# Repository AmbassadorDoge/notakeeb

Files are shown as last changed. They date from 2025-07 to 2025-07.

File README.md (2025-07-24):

# This is a Keyboard!

## Description
This is a 65% keyboard that I made to learn more about PCB design & keyboard making! It uses a Raspberry Pi Pico as its microcontroller and I plan to use Akko Penguin switches. On the bottom right of the PCB, there is artwork by [bunnyguy](https://bunnyguy.foo/)!

## Why I Made This
I need a keyboard, and I need to learn pcb design + F360, so why not fulfill both? I also thought this was a fun project, and I learned a lot from researching keyboard components and design! I guess this is a part 2 to the hackpad I made a week earlier.

## Why It's Cool
There are magnets on each side so that decals or wrist rests could be added for customization. There might be keyboard lifts in the making for those side mounts 👀

## Pictures
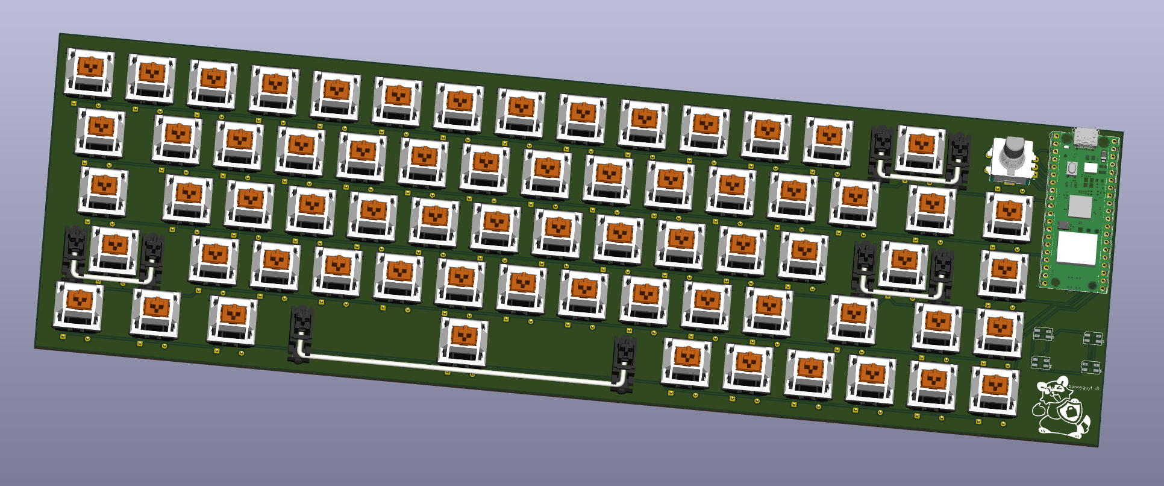
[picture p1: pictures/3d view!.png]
very good

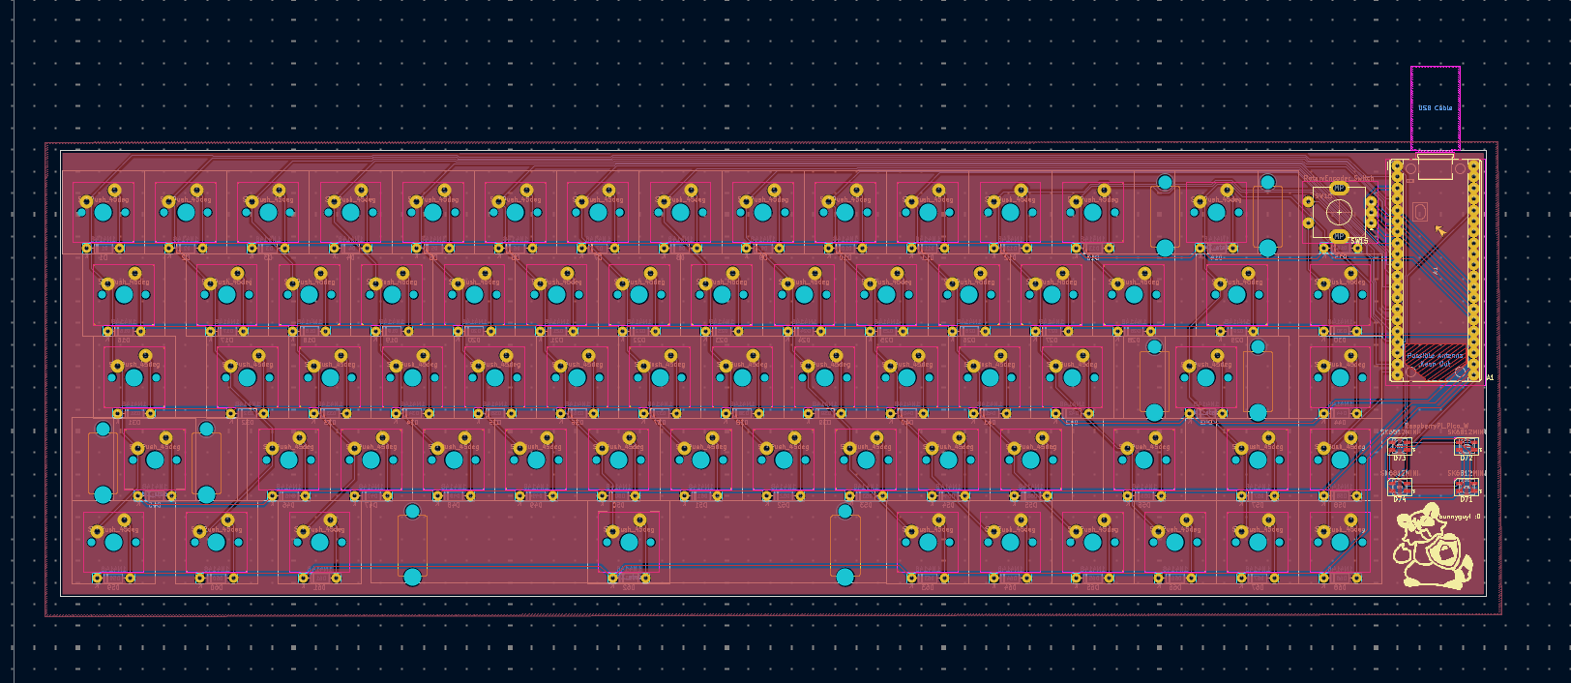
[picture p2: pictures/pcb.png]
good good good

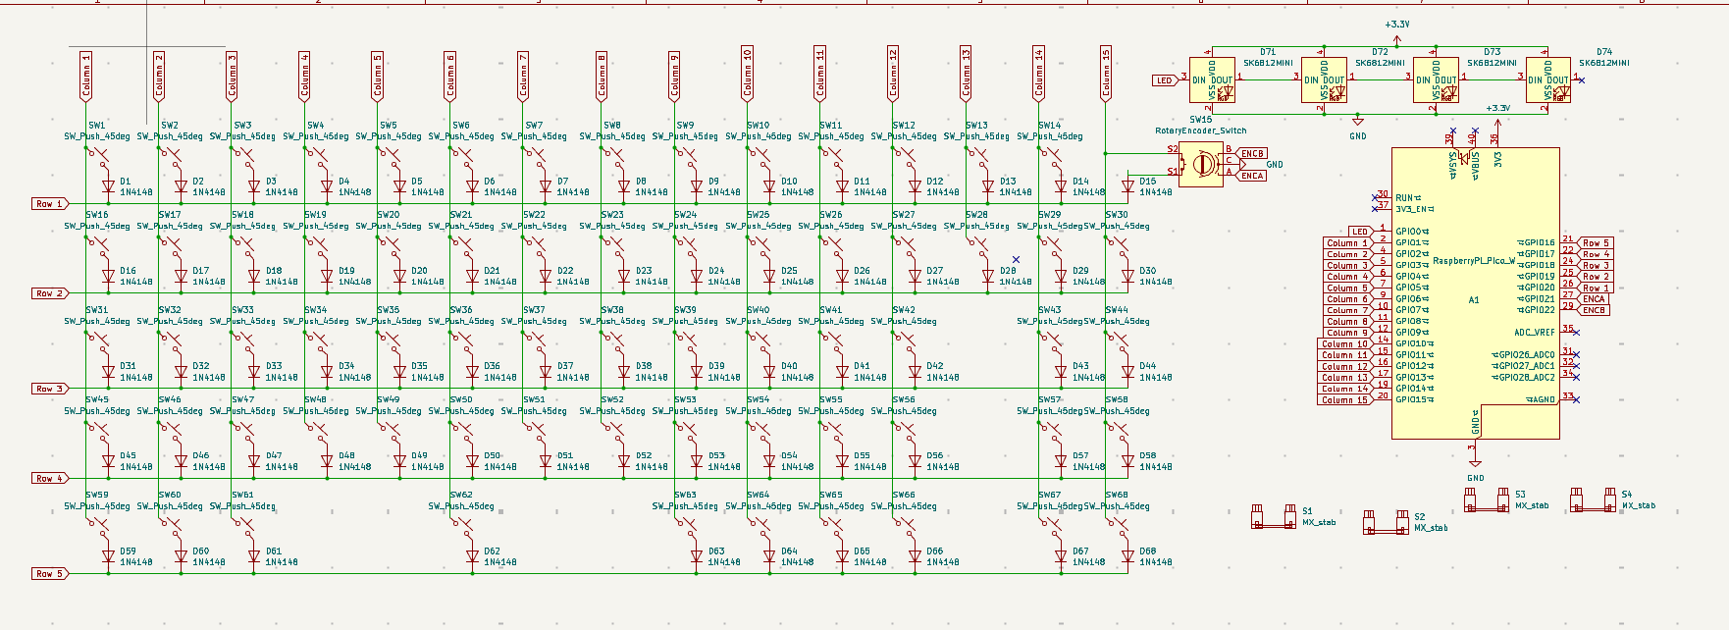
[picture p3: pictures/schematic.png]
good good

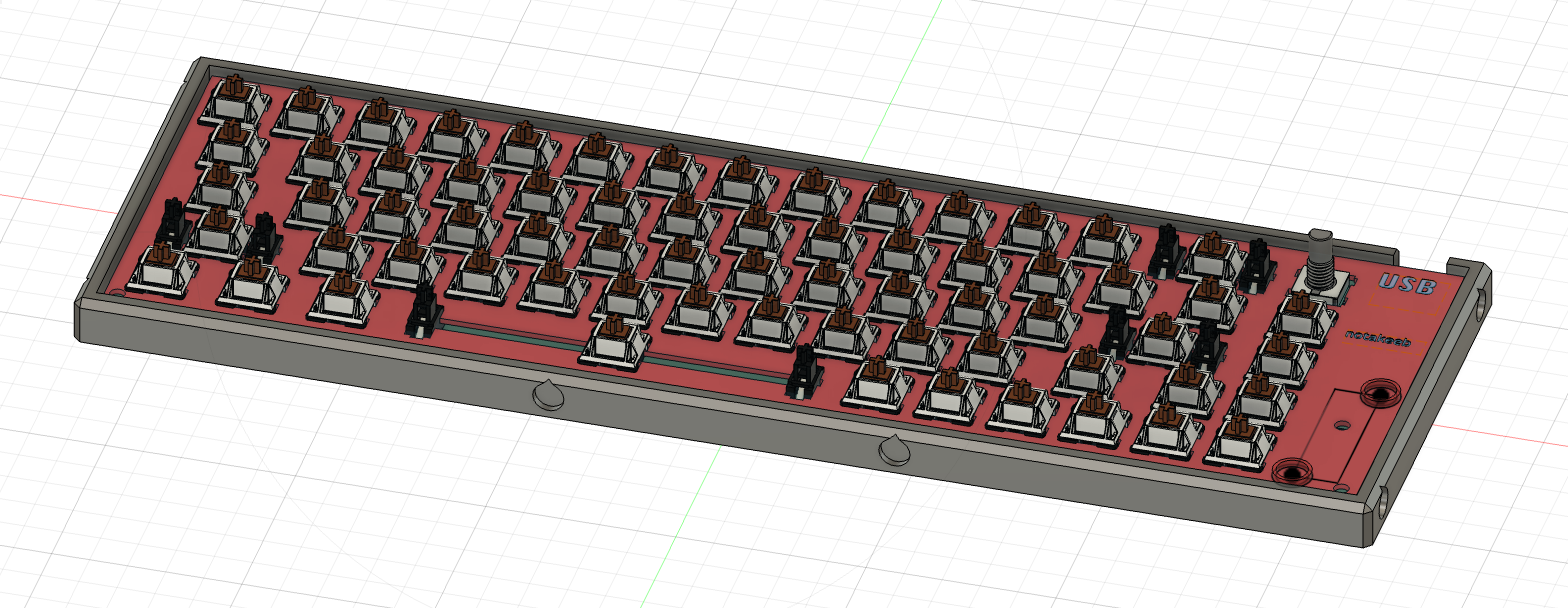
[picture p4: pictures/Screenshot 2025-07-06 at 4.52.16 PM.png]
fusionss

## BOM
| name | qty  | price  | link | notes |
| --- | ---- | --- | --- | --- |
| switches | 2 | 37.98  | [https://www.amazon.com/dp/B0CJY7QN11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](https://www.amazon.com/dp/B0CJY7QN11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) | awesome-mx style |
| keycaps | 1 | 20.5 | [https://www.amazon.com/Rainy75-Gradient-Minimalist-Keyboard-Mechanical/dp/B0F5GLMNFS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](https://www.amazon.com/Rainy75-Gradient-Minimalist-Keyboard-Mechanical/dp/B0F5GLMNFS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) | idk if these work |
| diodes | 1 | 5.99 | [https://www.amazon.com/BOJACK-Switching-IN4148-Electronic-Silicon/dp/B07Q4F3Y5W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](https://www.amazon.com/BOJACK-Switching-IN4148-Electronic-Silicon/dp/B07Q4F3Y5W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) | first thing popped up |
| board | 1 | 7.65 | [https://www.digikey.com/en/products/detail/raspberry-pi/SC0918/16627943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](https://www.digikey.com/en/products/detail/raspberry-pi/SC0918/16627943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) | i think this works |
| fasteners | 1 | 9.99 | [https://www.amazon.com/Mywish-Assortment-Stainless-Washers-Wrenche/dp/B0CQQS6STL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](https://www.amazon.com/Mywish-Assortment-Stainless-Washers-Wrenche/dp/B0CQQS6STL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) | m3 hopefully is good  |
| stabilizers | 1 | 18.99  | [https://www.amazon.com/DUROCK-Stabilizers-Translucent-Keyboard-Mechanical/dp/B0B2RVN19F?th=1](https://www.amazon.com/DUROCK-Stabilizers-Translucent-Keyboard-Mechanical/dp/B0B2RVN19F?th=1) | suggested |
| tape | 1 | 7.99 | [https://www.amazon.com/Resistant-Sublimation-Temperature-Electronics-Polyimide/dp/B07F8TZZ4N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](https://www.amazon.com/Resistant-Sublimation-Temperature-Electronics-Polyimide/dp/B07F8TZZ4N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) | |
| magnets | 1 | 4.51 | [https://www.aliexpress.us/item/3256808695821393.html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](https://www.aliexpress.us/item/3256808695821393.html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) | |
| pcb | 1(5) | 25.04  | | |
| | | 138.64 | 152.1574

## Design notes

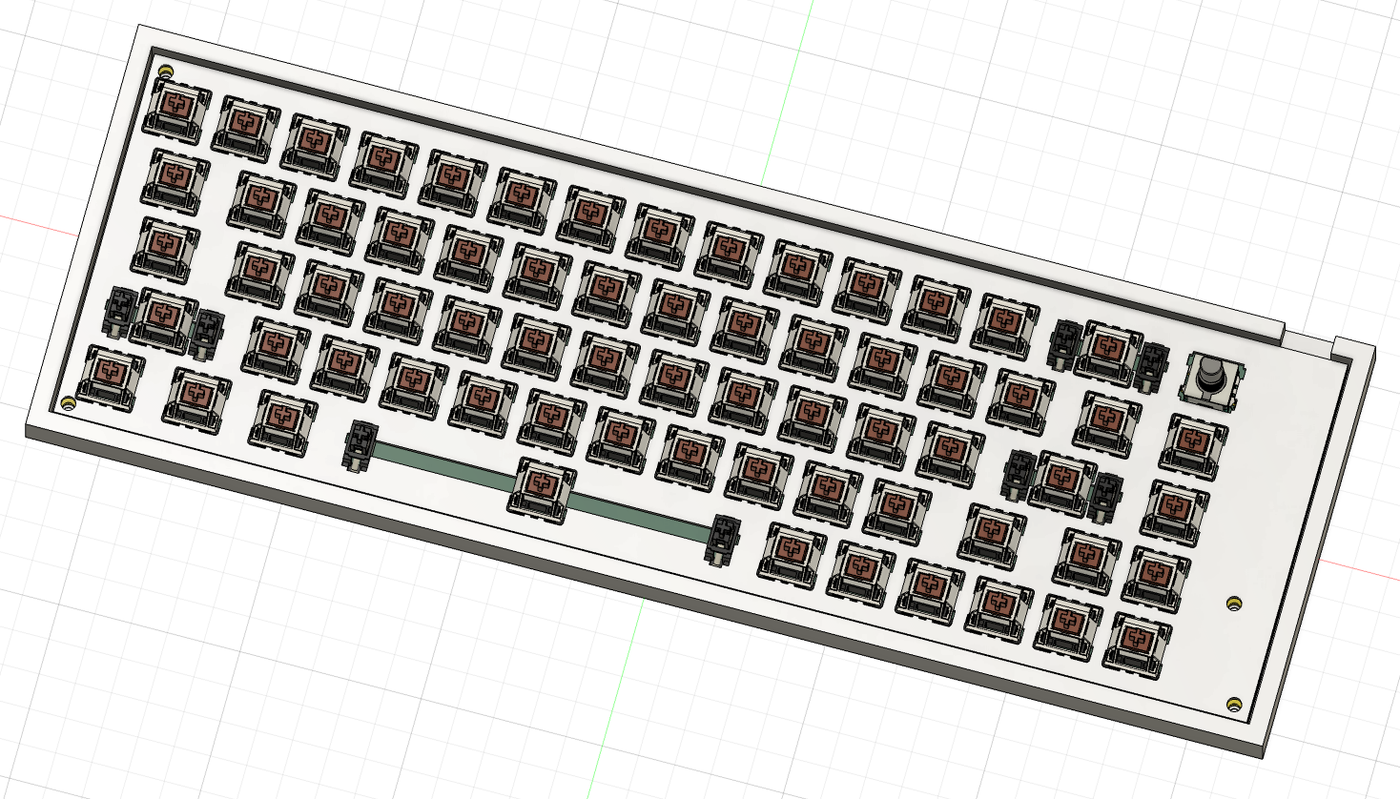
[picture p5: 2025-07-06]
pictures/Screenshot 2025-07-05 at 5.33.53 PM.png

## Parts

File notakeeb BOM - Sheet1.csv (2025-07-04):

name | qty | price | link | notes
switches | 2 | 37.98 | https://www.amazon.com/dp/B0CJY7QN11 | awesome-mx style
keycaps | 1 | 20.5 | https://www.amazon.com/Rainy75-Gradient-Minimalist-Keyboard-Mechanical/dp/B0F5GLMNFS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 | idk if these work
diodes | 1 | 5.99 | https://www.amazon.com/BOJACK-Switching-IN4148-Electronic-Silicon/dp/B07Q4F3Y5W | first thing popped up
board | 1 | 7.65 | https://www.digikey.com/en/products/detail/raspberry-pi/SC0918/16627943?gad_source=1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 | i think this works
fasteners | 1 | 9.99 | https://www.amazon.com/Mywish-Assortment-Stainless-Washers-Wrenche/dp/B0CQQS6STL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 | m3 hopefully is good
stabilizers | 1 | 18.99 | https://www.amazon.com/DUROCK-Stabilizers-Translucent-Keyboard-Mechanical/dp/B0B2RVN19F?th=1 | suggested
tape | 1 | 7.99 | https://www.amazon.com/Resistant-Sublimation-Temperature-Electronics-Polyimide/dp/B07F8TZZ4N
pcb | 1(5) | 25.04
 |  | 134.13

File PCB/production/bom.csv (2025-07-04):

Designator | Footprint | Quantity | Value | LCSC Part #
A1 | RaspberryPi_Pico_Common_THT | 1 | RaspberryPi_Pico_W
D1, D10, D11, D12, D13, D14, D15, D16, D17, D18, D19, D2, D20, D21, D22, D23, D24, D25, D26, D27, D28, D29, D3, D30, D31, D32, D33, D34, D35, D36, D37, D38, D39, D4, D40, D41, D42, D43, D44, D45, D46, D47, D48, D49, D5, D50, D51, D52, D53, D54, D55, D56, D57, D58, D59, D6, D60, D61, D62, D63, D64, D65, D66, D67, D68, D7, D8, D9 | D_DO-35_SOD27_P7.62mm_Horizontal | 68 | 1N4148
D71, D72, D73, D74 | LED_SK6812MINI_PLCC4_3.5x3.5mm_P1.75mm | 4 | SK6812MINI
S1, S2, S4 | STAB_MX_2u | 3 | MX_stab
S3 | STAB_MX_6.25u | 1 | MX_stab
SW1, SW10, SW11, SW12, SW13, SW14, SW16, SW17, SW18, SW19, SW2, SW20, SW21, SW22, SW23, SW24, SW25, SW26, SW27, SW28, SW29, SW3, SW30, SW31, SW32, SW33, SW34, SW35, SW36, SW37, SW38, SW39, SW4, SW40, SW41, SW42, SW43, SW44, SW45, SW46, SW47, SW48, SW49, SW5, SW50, SW51, SW52, SW53, SW54, SW55, SW56, SW57, SW58, SW59, SW6, SW60, SW61, SW62, SW63, SW64, SW65, SW66, SW67, SW68, SW7, SW8, SW9 | SW_MX_1u | 67 | SW_Push_45deg
SW15 | RotaryEncoder_Alps_EC11E-Switch_Vertical_H20mm | 1 | RotaryEncoder_Switch

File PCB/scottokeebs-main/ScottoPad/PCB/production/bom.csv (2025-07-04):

Designator | Footprint | Quantity | Value | LCSC Part #
C0, C1, C2, C3, C4, C5, R0, R1, R2 | TestPoint | 9 | TestPoint
D1, D10, D11, D12, D13, D14, D15, D16, D17, D18, D2, D3, D4, D5, D6, D7, D8, D9 | Diode_SOD-123 | 18 | Diode
S1, S10, S11, S12, S13, S14, S15, S16, S17, S18, S2, S3, S4, S5, S6, S7, S8, S9 | MX_Solder_1.00u | 18 | Keyswitch

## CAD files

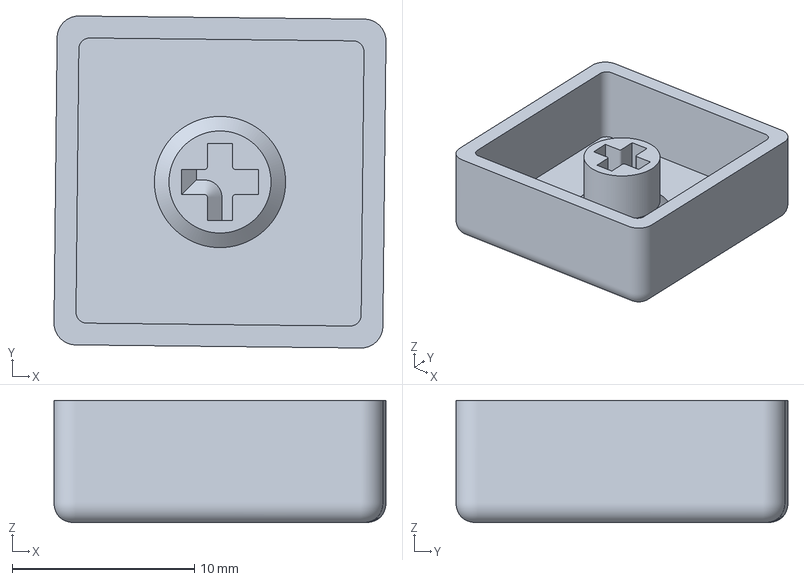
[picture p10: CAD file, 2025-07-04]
PCB/scottokeebs-main/Extras/ScottoCaps/Flat/Legends/Slash.3mf
18.2 x 18.2 x 6.70 mm
Slash_Keycap
Slash_Text

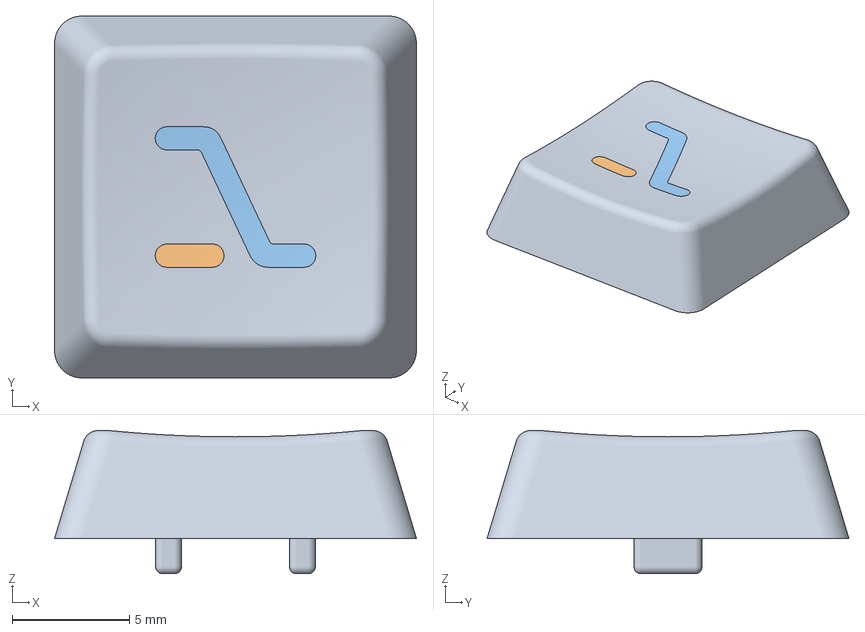
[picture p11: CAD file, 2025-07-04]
PCB/scottokeebs-main/Extras/ScottoCaps/Scooped/Choc/Legends/16x16/Option - Icon (16x16).3mf
15.4 x 15.4 x 6.11 mm
Keycap

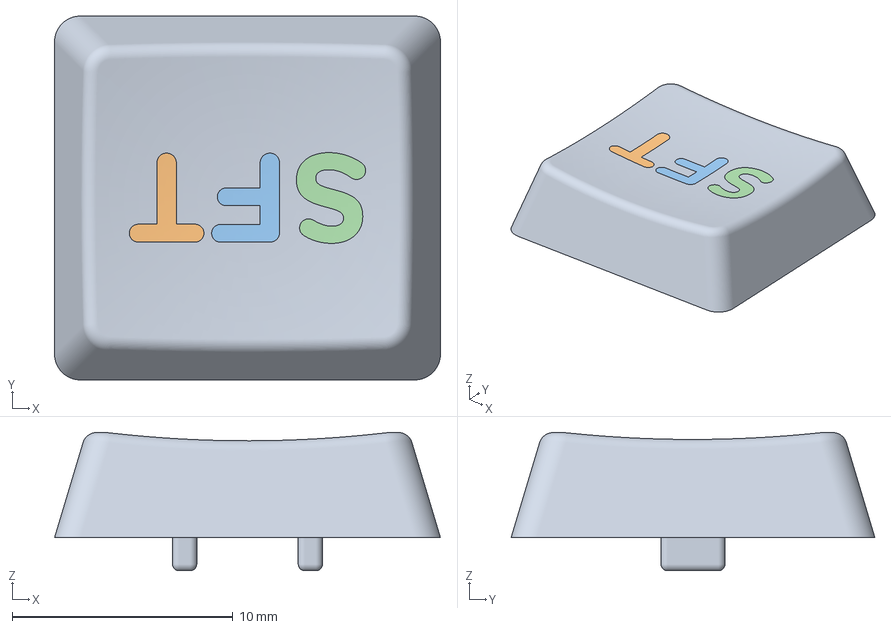
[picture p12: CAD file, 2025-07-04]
PCB/scottokeebs-main/Extras/ScottoCaps/Scooped/Choc/Legends/18x17/Shift (18x17).3mf
17.5 x 16.5 x 6.28 mm
Keycap
T
F
S

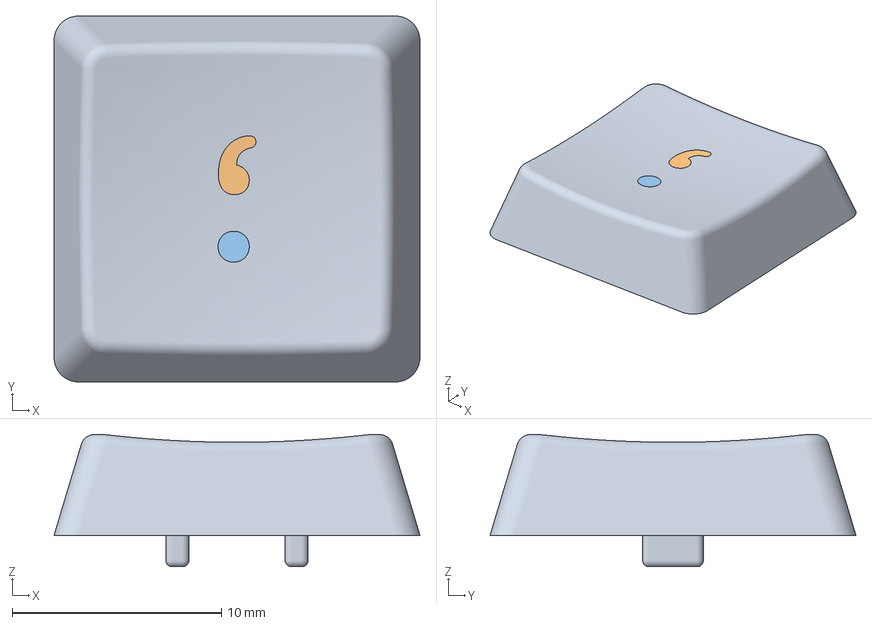
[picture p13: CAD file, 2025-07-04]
PCB/scottokeebs-main/Extras/ScottoCaps/Scooped/Choc/Legends/18x18/Semicolon (18x18).3mf
17.5 x 17.5 x 6.33 mm
Keycap

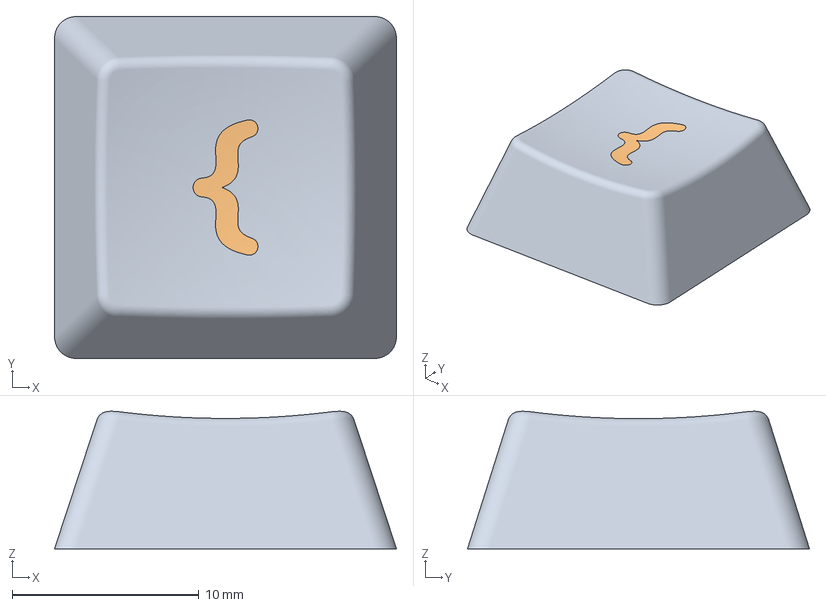
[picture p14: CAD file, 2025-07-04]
PCB/scottokeebs-main/Extras/ScottoCaps/Scooped/MX/Legends/Curly Bracket.3mf
18.3 x 18.3 x 7.36 mm
Keycap
Legend

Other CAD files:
CAD/notakeeb top v6.step
PCB/marbastlib-main/3dmodels/CON_2121340004.step
PCB/scottokeebs-main/Extras/ScottoBender/ScottoBender - Top.step
PCB/scottokeebs-main/Extras/ScottoBender/V1/ScottoBender - ScottoBender (18g).step
PCB/scottokeebs-main/Extras/ScottoCaps/Flat/Blanks/7.00u.step
PCB/scottokeebs-main/Extras/ScottoCaps/Glass/Choc/ScottoCaps (Glass) - 1.00u.step
PCB/scottokeebs-main/Extras/ScottoCaps/Glass/MX/ScottoCaps (Glass) - 2.25u.step
PCB/scottokeebs-main/Extras/ScottoCaps/Scooped/Choc/Blanks/16x16/1.25u (16x16 - Concave).step
PCB/scottokeebs-main/Extras/ScottoCaps/Scooped/Choc/Blanks/18x17/1.00u (18x17 - Domed - Convex).step
PCB/scottokeebs-main/Extras/ScottoCaps/Scooped/Choc/Blanks/18x18/1.00u (18x18 - Convex).step
PCB/scottokeebs-main/Extras/ScottoCaps/Scooped/MX/Blanks/1.50u (Concave).step
PCB/scottokeebs-main/Extras/ScottoCaps/Scooped/MX/ScottoCaps (Scooped - MX) - Raw.step
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

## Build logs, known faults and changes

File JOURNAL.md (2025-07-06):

---
title: "not a keeb"
author: "Doge"
description: "It is a keyboard!"
created_at: "2025-06-28"
---

**Total Total time spent: 15h**

### Day 1 | 6/29 | PCB Pain
- Did a heck ton of research on what a mechanical keyboard is + components
- asked around in #highway for help on part sourcing: decided on Akko Penguins on 65%
- Started schematic (14x5 + 1 rotary encoder + pico) + pcb work
- Realized my routing is messy and restarted, then realized that it could be much simpler with better schematic wiring
    - Changed to 15x5 and removed some switches for bigger keys
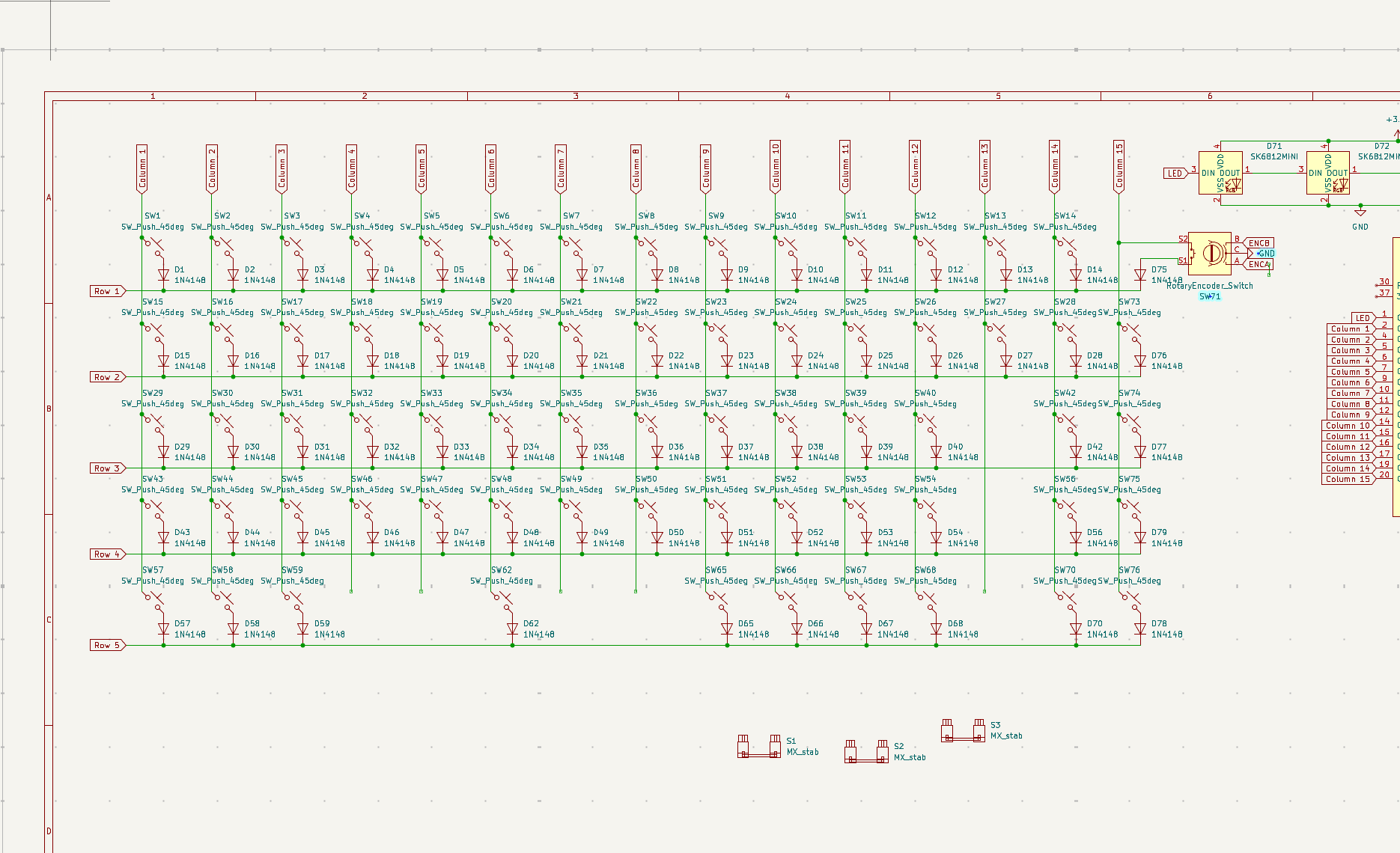
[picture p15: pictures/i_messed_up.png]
I really messed up

    - Then realized that the numbering mechanism for kbplacer got messed up because of it :sob:
- Overall, I learned and set my goals!

**Total hours spent: 5h**

### Day 2 | 6/30 | Fresh Start!
- Restarted the switches matrix so the numbering would be fixed!
good good
- Routed correctly this time
good good good
- Spent an unhealthy amount of time navigating KiCad to find where to add 3D Models :(
very good
- More research + BOM making

**Total hours spent: 5h** 

### Day 3 | 7/1 | Hopefully almost done!
- Double checked PCB
- Learning Fusion360! It's my first time, and I have only used SolidWorks and Onshape before
    - I realize that I dislike fusion, it is so slow!

**Total hours spent: 1h**

### Day 4 | 7/2 | Finished!
- Finished the case! I plan to use heat set inserts so screwing in the PCB would be easier
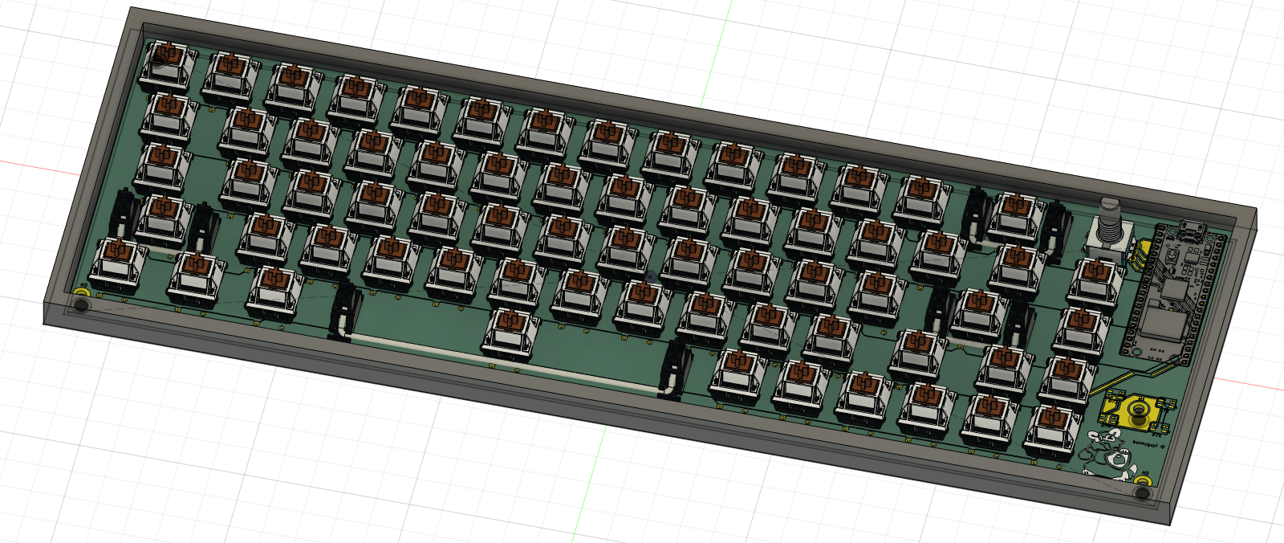
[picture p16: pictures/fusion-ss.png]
hi


**Total hours spent: 1h**

### Day 5 | 7/4 | Commits...
- Organized files + wrote stuff
- Spent a sad amount of time learning git and almost breaking stuff...
- Firmware through ai

**Total hours spent: 1h**

### Day 6 | 7/6 | Fixes!
- Committed fixes needed for re-review!
    - Added top to case
    sc
    - Added teardrop holes for magnets + logos&text

**Total hours spent: 2h**

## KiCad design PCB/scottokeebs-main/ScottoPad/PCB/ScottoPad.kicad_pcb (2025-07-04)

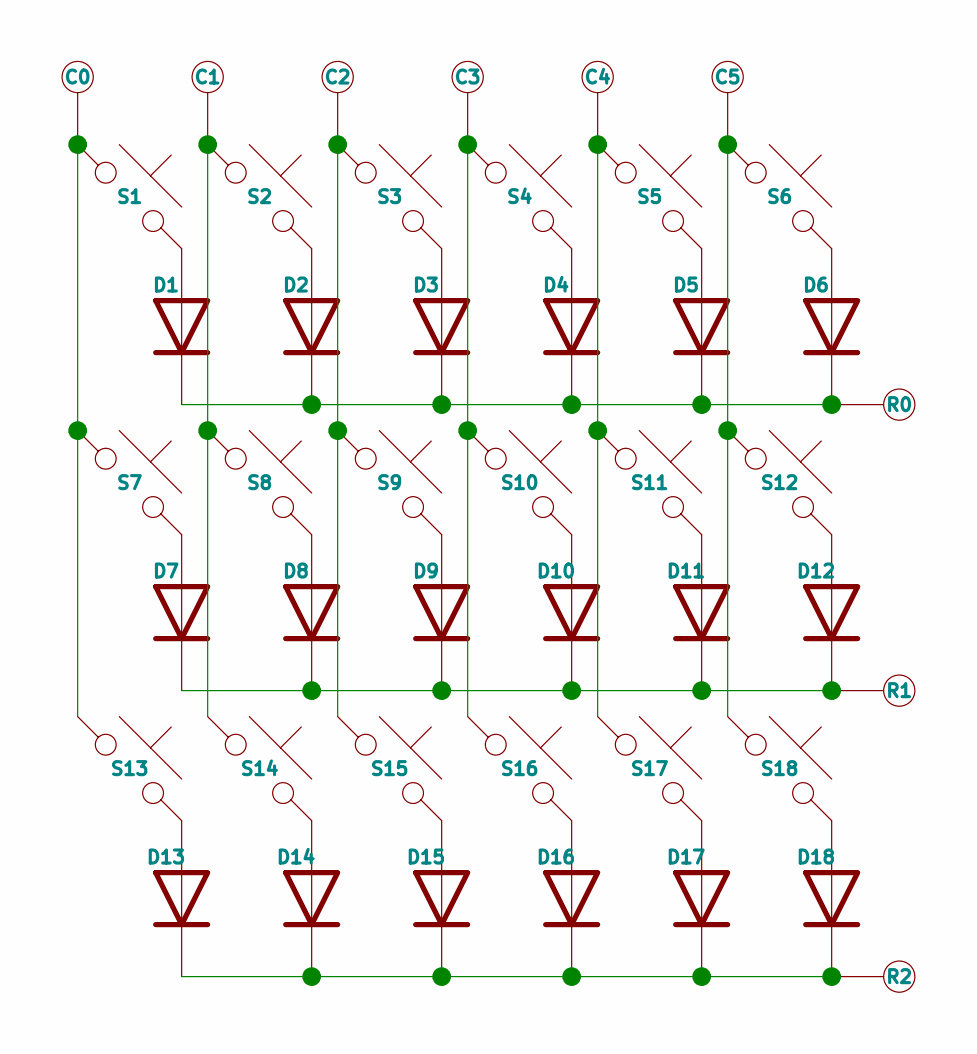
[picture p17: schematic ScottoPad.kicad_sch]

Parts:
C0, C1, C2, C3, C4, C5: TestPoint
D1, D2, D3, D4, D5, D6, D7, D8, D9, D10, D11, D12, D13, D14, D15, D16, D17, D18: Diode; Diode_SOD-123
R0, R1, R2: TestPoint
S1, S2, S3, S4, S5, S6, S7, S8, S9, S10, S11, S12, S13, S14, S15, S16, S17, S18: Keyswitch; MX_Solder_1.00u

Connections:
unnamed: C0.1, S1.1, S7.1, S13.1
unnamed: C1.1, S2.1, S8.1, S14.1
unnamed: C2.1, S3.1, S9.1, S15.1
unnamed: C3.1, S4.1, S10.1, S16.1
unnamed: C4.1, S5.1, S11.1, S17.1
unnamed: C5.1, S6.1, S12.1, S18.1
unnamed: D1.2 (A), S1.2
unnamed: D1.1 (K), D2.1 (K), D3.1 (K), D4.1 (K), D5.1 (K), D6.1 (K), R0.1
unnamed: D2.2 (A), S2.2
unnamed: D3.2 (A), S3.2
unnamed: D4.2 (A), S4.2
unnamed: D5.2 (A), S5.2
unnamed: D6.2 (A), S6.2
unnamed: D7.2 (A), S7.2
unnamed: D8.2 (A), S8.2
unnamed: D9.2 (A), S9.2
unnamed: D10.2 (A), S10.2
unnamed: D7.1 (K), D8.1 (K), D9.1 (K), D10.1 (K), D11.1 (K), D12.1 (K), R1.1
unnamed: D11.2 (A), S11.2
unnamed: D12.2 (A), S12.2
unnamed: D13.2 (A), S13.2
unnamed: D13.1 (K), D14.1 (K), D15.1 (K), D16.1 (K), D17.1 (K), D18.1 (K), R2.1
unnamed: D14.2 (A), S14.2
unnamed: D15.2 (A), S15.2
unnamed: D16.2 (A), S16.2
unnamed: D17.2 (A), S17.2
unnamed: D18.2 (A), S18.2

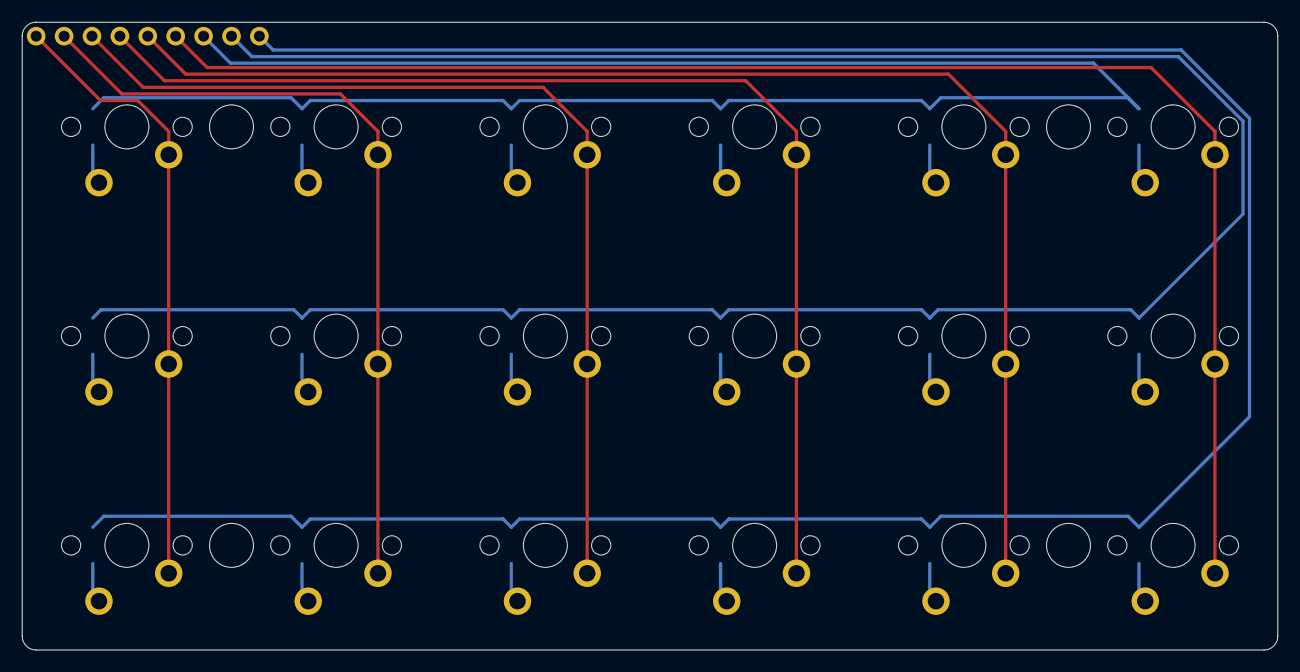
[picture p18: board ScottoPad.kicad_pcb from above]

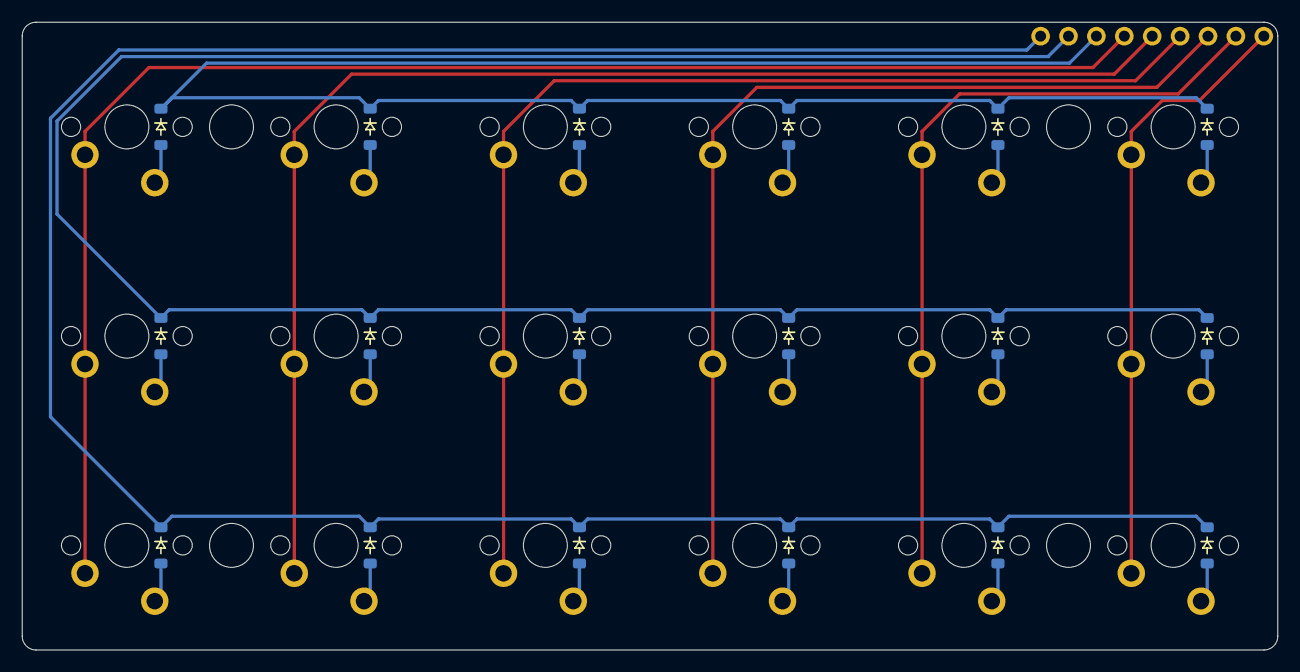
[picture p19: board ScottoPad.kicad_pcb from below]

Board: 2 copper layers, 114.3 x 57.2 mm, 45 parts (18 on the bottom side), 27 nets.

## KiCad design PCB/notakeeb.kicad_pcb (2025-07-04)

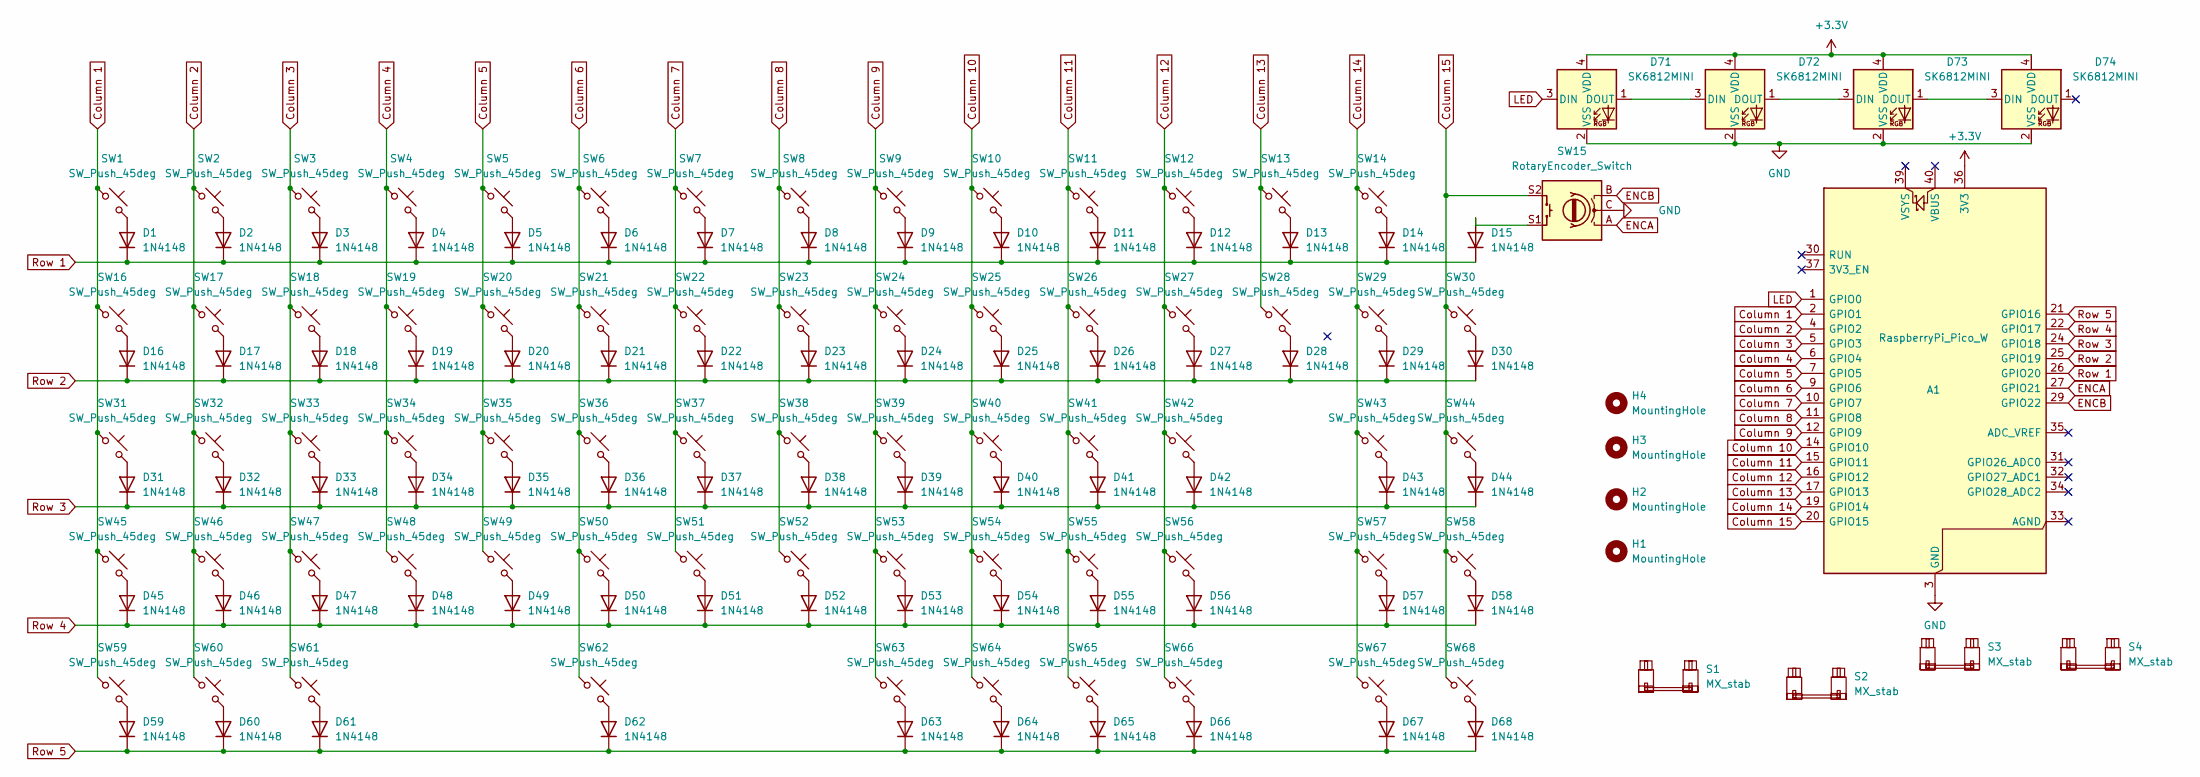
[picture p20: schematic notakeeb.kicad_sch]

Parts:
A1: RaspberryPi_Pico_W; RaspberryPi_Pico_Common_THT
D1, D2, D3, D4, D5, D6, D7, D8, D9, D10, D11, D12, D13, D14, D15, D16, D17, D18, D19, D20, D21, D22, D23, D24, D25, D26, D27, D28, D29, D30, D31, D32, D33, D34, D35, D36, D37, D38, D39, D40, D41, D42, D43, D44, D45, D46, D47, D48, D49, D50, D51, D52, D53, D54, D55, D56, D57, D58, D59, D60, D61, D62, D63, D64, D65, D66, D67, D68: 1N4148; D_DO-35_SOD27_P7.62mm_Horizontal
D71, D72, D73, D74: SK6812MINI; LED_SK6812MINI_PLCC4_3.5x3.5mm_P1.75mm
H1, H2, H3, H4: MountingHole; MountingHole_3.2mm_M3_DIN965_Pad_TopBottom
S1, S2, S4: MX_stab; STAB_MX_2u
S3: MX_stab; STAB_MX_6.25u
SW1, SW2, SW3, SW4, SW5, SW6, SW7, SW8, SW9, SW10, SW11, SW12, SW13, SW14, SW16, SW17, SW18, SW19, SW20, SW21, SW22, SW23, SW24, SW25, SW26, SW27, SW28, SW29, SW30, SW31, SW32, SW33, SW34, SW35, SW36, SW37, SW38, SW39, SW40, SW41, SW42, SW43, SW44, SW45, SW46, SW47, SW48, SW49, SW50, SW51, SW52, SW53, SW54, SW55, SW56, SW57, SW58, SW59, SW60, SW61, SW62, SW63, SW64, SW65, SW66, SW67, SW68: SW_Push_45deg; SW_MX_1u
SW15: RotaryEncoder_Switch; RotaryEncoder_Alps_EC11E-Switch_Vertical_H20mm

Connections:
+3.3V: A1.36 (3V3), D71.4 (VDD), D72.4 (VDD), D73.4 (VDD), D74.4 (VDD)
Column 1: A1.2 (GPIO1), SW1.1, SW16.1, SW31.1, SW45.1, SW59.1
Column 2: A1.4 (GPIO2), SW2.1, SW17.1, SW32.1, SW46.1, SW60.1
Column 3: A1.5 (GPIO3), SW3.1, SW18.1, SW33.1, SW47.1, SW61.1
Column 4: A1.6 (GPIO4), SW4.1, SW19.1, SW34.1, SW48.1
Column 5: A1.7 (GPIO5), SW5.1, SW20.1, SW35.1, SW49.1
Column 6: A1.9 (GPIO6), SW6.1, SW21.1, SW36.1, SW50.1, SW62.1
Column 7: A1.10 (GPIO7), SW7.1, SW22.1, SW37.1, SW51.1
Column 8: A1.11 (GPIO8), SW8.1, SW23.1, SW38.1, SW52.1
Column 9: A1.12 (GPIO9), SW9.1, SW24.1, SW39.1, SW53.1, SW63.1
Column 10: A1.14 (GPIO10), SW10.1, SW25.1, SW40.1, SW54.1, SW64.1
Column 11: A1.15 (GPIO11), SW11.1, SW26.1, SW41.1, SW55.1, SW65.1
Column 12: A1.16 (GPIO12), SW12.1, SW27.1, SW42.1, SW56.1, SW66.1
Column 13: A1.17 (GPIO13), SW13.1, SW28.1
Column 14: A1.19 (GPIO14), SW14.1, SW29.1, SW43.1, SW57.1, SW67.1
Column 15: A1.20 (GPIO15), SW15.S2, SW30.1, SW44.1, SW58.1, SW68.1
ENCA: A1.27 (GPIO21), SW15.A
ENCB: A1.29 (GPIO22), SW15.B
GND: A1.3 (GND), A1.8 (GND), A1.13 (GND), A1.18 (GND), A1.23 (GND), A1.28 (GND), A1.38 (GND), D71.2 (VSS), D72.2 (VSS), D73.2 (VSS), D74.2 (VSS), SW15.C
LED: A1.1 (GPIO0), D71.3 (DIN)
unnamed: D1.2 (A), SW1.2
unnamed: D2.2 (A), SW2.2
unnamed: D3.2 (A), SW3.2
unnamed: D4.2 (A), SW4.2
unnamed: D5.2 (A), SW5.2
unnamed: D6.2 (A), SW6.2
unnamed: D7.2 (A), SW7.2
unnamed: D8.2 (A), SW8.2
unnamed: D9.2 (A), SW9.2
unnamed: D10.2 (A), SW10.2
unnamed: D11.2 (A), SW11.2
unnamed: D12.2 (A), SW12.2
unnamed: D13.2 (A), SW13.2
unnamed: D14.2 (A), SW14.2
unnamed: D15.2 (A), SW15.S1
unnamed: D16.2 (A), SW16.2
unnamed: D17.2 (A), SW17.2
unnamed: D18.2 (A), SW18.2
unnamed: D19.2 (A), SW19.2
unnamed: D20.2 (A), SW20.2
unnamed: D21.2 (A), SW21.2
unnamed: D22.2 (A), SW22.2
unnamed: D23.2 (A), SW23.2
unnamed: D24.2 (A), SW24.2
unnamed: D25.2 (A), SW25.2
unnamed: D26.2 (A), SW26.2
unnamed: D27.2 (A), SW27.2
unnamed: D28.2 (A), SW28.2
unnamed: D29.2 (A), SW29.2
unnamed: D30.2 (A), SW30.2
unnamed: D31.2 (A), SW31.2
unnamed: D32.2 (A), SW32.2
unnamed: D33.2 (A), SW33.2
unnamed: D34.2 (A), SW34.2
unnamed: D35.2 (A), SW35.2
unnamed: D36.2 (A), SW36.2
unnamed: D37.2 (A), SW37.2
unnamed: D38.2 (A), SW38.2
unnamed: D39.2 (A), SW39.2
unnamed: D40.2 (A), SW40.2
unnamed: D41.2 (A), SW41.2
unnamed: D42.2 (A), SW42.2
unnamed: D43.2 (A), SW43.2
unnamed: D44.2 (A), SW44.2
unnamed: D45.2 (A), SW45.2
unnamed: D46.2 (A), SW46.2
unnamed: D47.2 (A), SW47.2
unnamed: D48.2 (A), SW48.2
unnamed: D49.2 (A), SW49.2
unnamed: D50.2 (A), SW50.2
unnamed: D51.2 (A), SW51.2
unnamed: D52.2 (A), SW52.2
unnamed: D53.2 (A), SW53.2
unnamed: D54.2 (A), SW54.2
unnamed: D55.2 (A), SW55.2
unnamed: D56.2 (A), SW56.2
unnamed: D57.2 (A), SW57.2
unnamed: D58.2 (A), SW58.2
unnamed: D59.2 (A), SW59.2
unnamed: D60.2 (A), SW60.2
unnamed: D61.2 (A), SW61.2
unnamed: D62.2 (A), SW62.2
unnamed: D63.2 (A), SW63.2
unnamed: D64.2 (A), SW64.2
unnamed: D65.2 (A), SW65.2
unnamed: D66.2 (A), SW66.2
unnamed: D67.2 (A), SW67.2
unnamed: D68.2 (A), SW68.2
unnamed: D71.1 (DOUT), D72.3 (DIN)
unnamed: D72.1 (DOUT), D73.3 (DIN)
unnamed: D73.1 (DOUT), D74.3 (DIN)
Row 1: A1.26 (GPIO20), D1.1 (K), D2.1 (K), D3.1 (K), D4.1 (K), D5.1 (K), D6.1 (K), D7.1 (K), D8.1 (K), D9.1 (K), D10.1 (K), D11.1 (K), D12.1 (K), D13.1 (K), D14.1 (K), D15.1 (K)
Row 2: A1.25 (GPIO19), D16.1 (K), D17.1 (K), D18.1 (K), D19.1 (K), D20.1 (K), D21.1 (K), D22.1 (K), D23.1 (K), D24.1 (K), D25.1 (K), D26.1 (K), D27.1 (K), D28.1 (K), D29.1 (K), D30.1 (K)
Row 3: A1.24 (GPIO18), D31.1 (K), D32.1 (K), D33.1 (K), D34.1 (K), D35.1 (K), D36.1 (K), D37.1 (K), D38.1 (K), D39.1 (K), D40.1 (K), D41.1 (K), D42.1 (K), D43.1 (K), D44.1 (K)
Row 4: A1.22 (GPIO17), D45.1 (K), D46.1 (K), D47.1 (K), D48.1 (K), D49.1 (K), D50.1 (K), D51.1 (K), D52.1 (K), D53.1 (K), D54.1 (K), D55.1 (K), D56.1 (K), D57.1 (K), D58.1 (K)
Row 5: A1.21 (GPIO16), D59.1 (K), D60.1 (K), D61.1 (K), D62.1 (K), D63.1 (K), D64.1 (K), D65.1 (K), D66.1 (K), D67.1 (K), D68.1 (K)

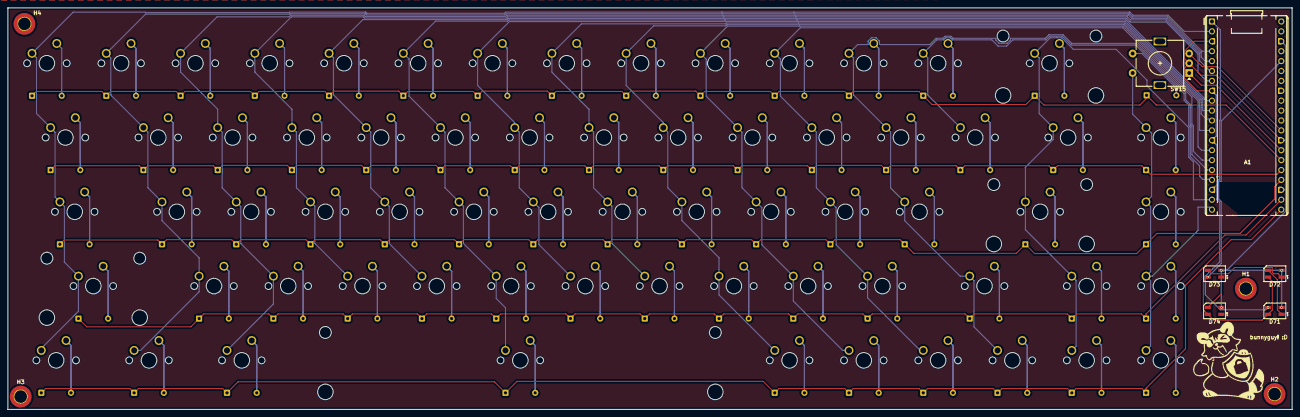
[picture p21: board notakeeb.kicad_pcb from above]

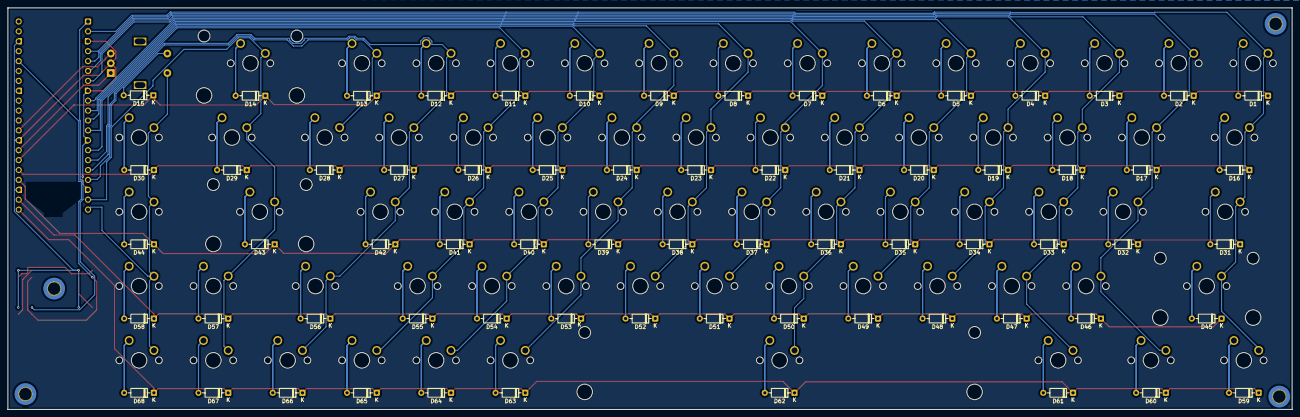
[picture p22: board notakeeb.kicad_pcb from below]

Board: 2 copper layers, 329.4 x 103.0 mm, 149 parts (68 on the bottom side), 96 nets.

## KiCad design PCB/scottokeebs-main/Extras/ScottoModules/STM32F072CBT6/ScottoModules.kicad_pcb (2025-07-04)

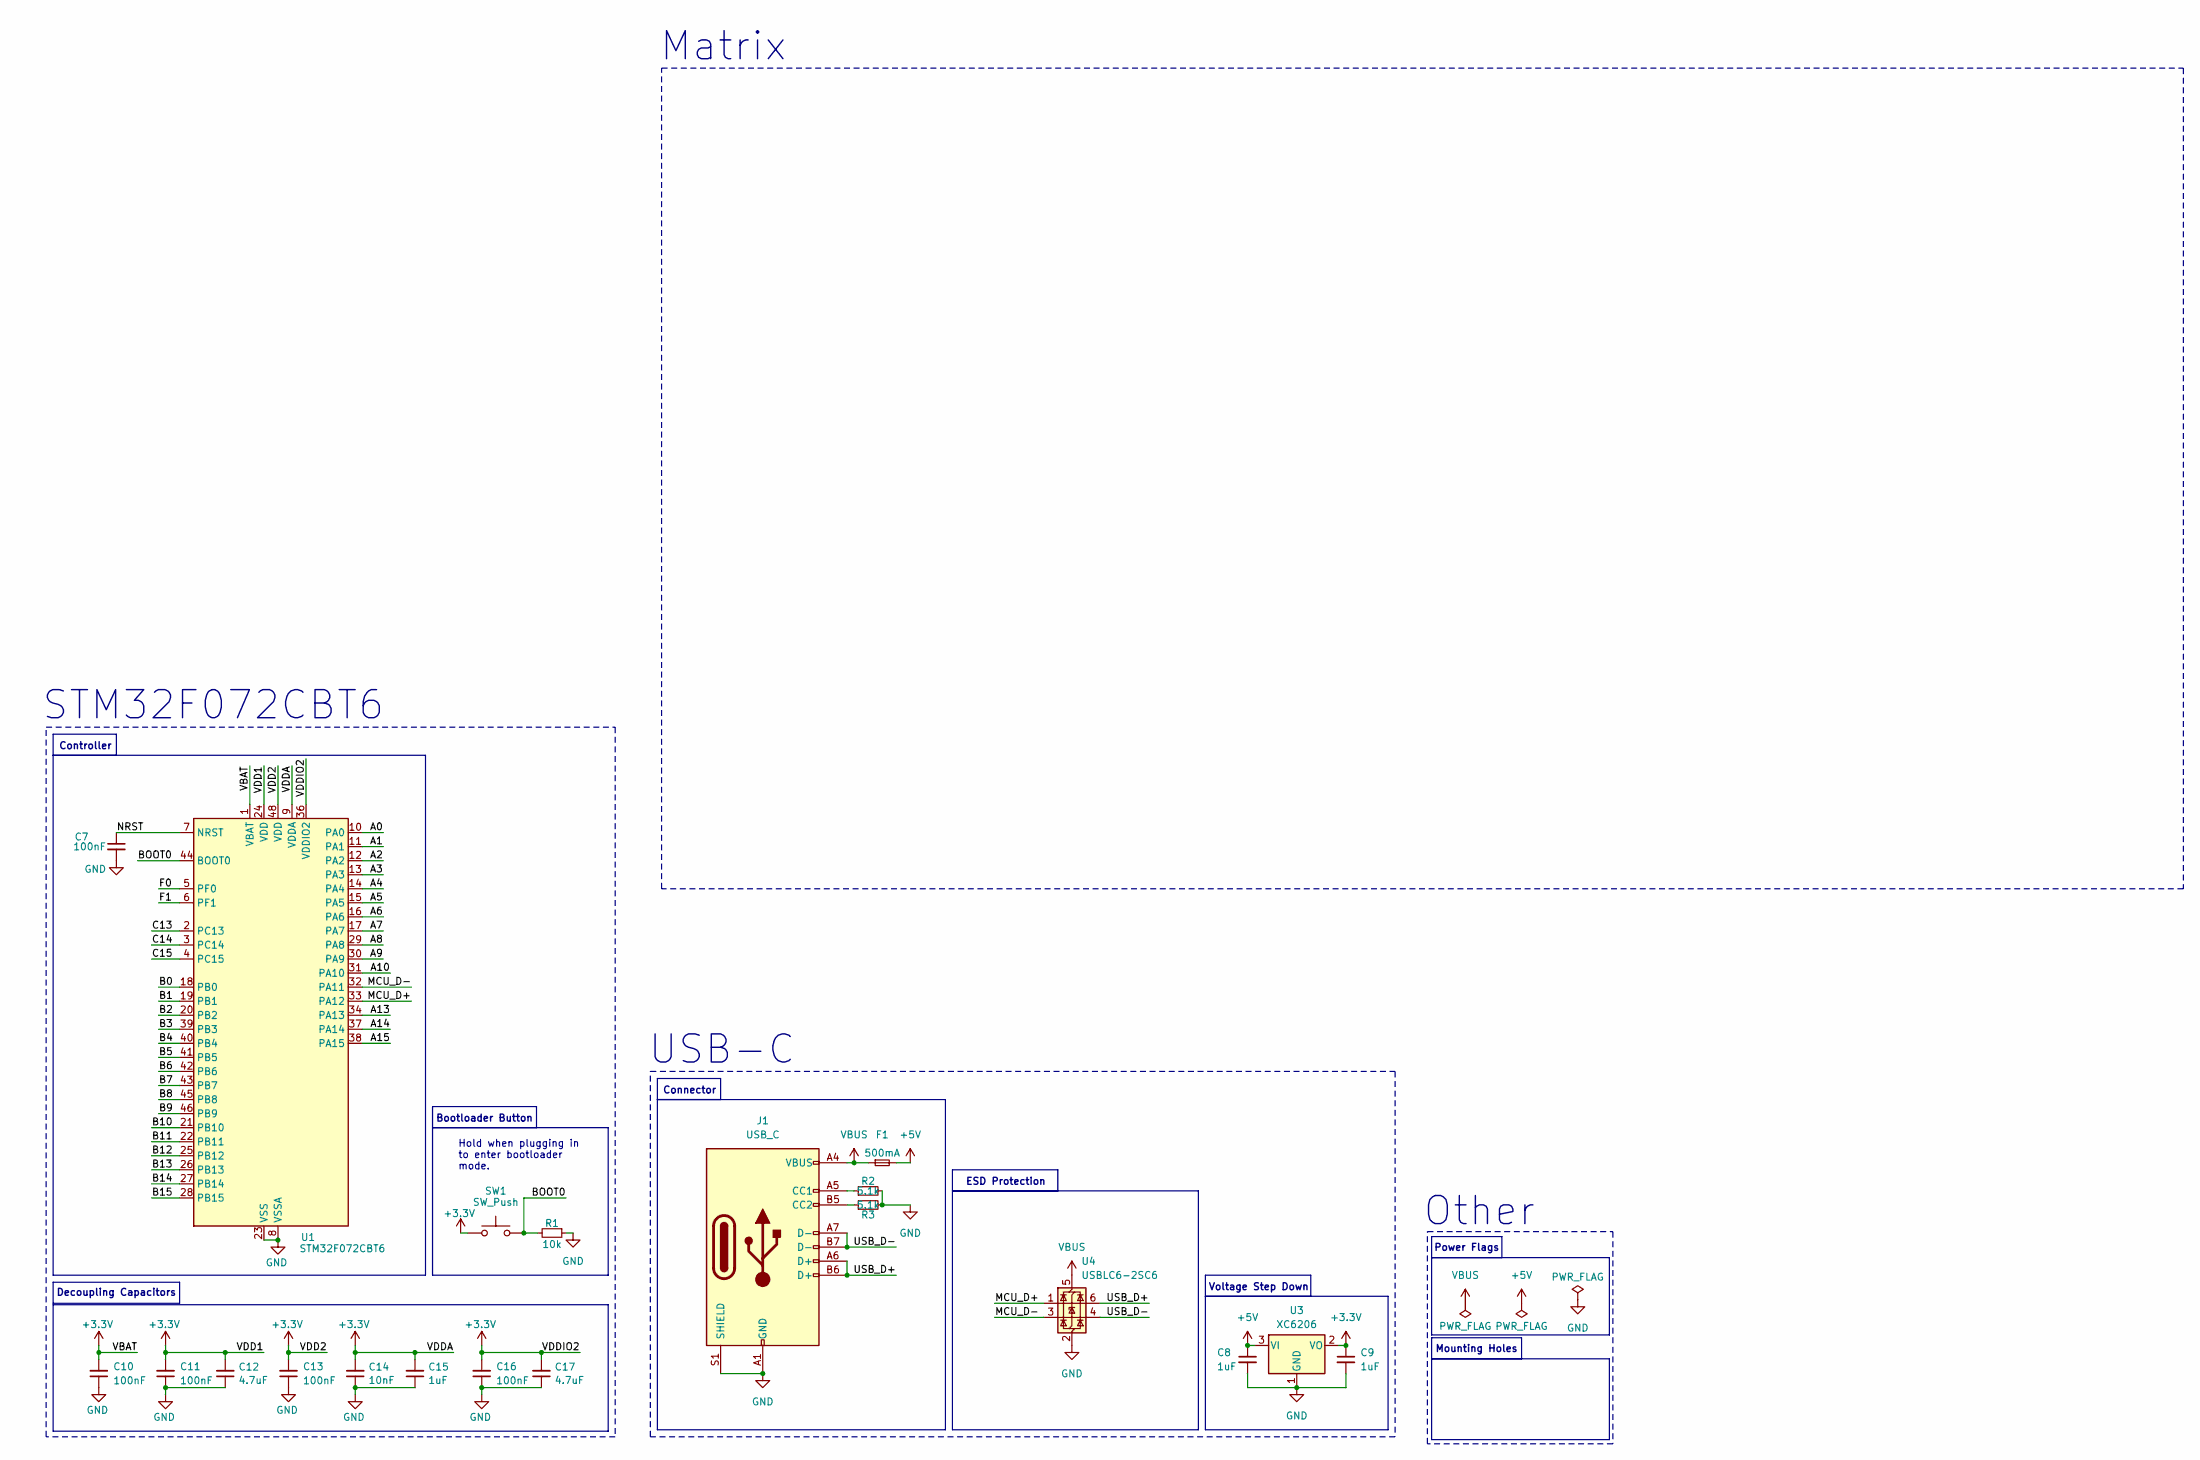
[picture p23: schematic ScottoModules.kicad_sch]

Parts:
C7: 100nF; Capacitor_0402; LCSC C307331
C8, C9: 1uF; Capacitor_0402; LCSC C52923
C10, C11, C13, C16: 100nF; Capacitor_0402; MPN CL05B104KB54PNC; LCSC C307331
C12, C17: 4.7uF; Capacitor_0402; MPN CL05A475MP5NRNC; LCSC C23733
C14: 10nF; Capacitor_0402; MPN CL05B103KB5NNNC; LCSC C15195
C15: 1uF; Capacitor_0402; MPN CL05A105KA5NQNC; LCSC C52923
F1: 500mA; Fuse_0603; LCSC C210357
J1: USB_C; USB_C_HRO_TYPE-C-31-M-12; LCSC C165948
R1: 10k; Resistor_0402; LCSC C25744
R2, R3: 5.1k; Resistor_0402; LCSC C25905
SW1: SW_Push; Button_TL3342; LCSC C115351
U1: STM32F072CBT6; Package_LQFP-48_7x7mm_P0.5; LCSC C81720
U3: XC6206; Voltage_SOT-23; LCSC C5446
U4: USBLC6-2SC6; ESD_SOT-23-6; LCSC C2827654

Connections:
+3.3V: C9.1, C10.2, C11.2, C12.2, C13.2, C14.2, C15.2, C16.2, C17.2, SW1.1, U1.1 (VBAT), U1.9 (VDDA), U1.24 (VDD), U1.36 (VDDIO2), U1.48 (VDD), U3.2 (VO)
+5V: C8.1, F1.2, U3.3 (VI)
/A0: U1.10 (PA0)
/A1: U1.11 (PA1)
/A2: U1.12 (PA2)
/A3: U1.13 (PA3)
/A4: U1.14 (PA4)
/A5: U1.15 (PA5)
/A6: U1.16 (PA6)
/A7: U1.17 (PA7)
/A8: U1.29 (PA8)
/A9: U1.30 (PA9)
/A10: U1.31 (PA10)
/A13: U1.34 (PA13)
/A14: U1.37 (PA14)
/A15: U1.38 (PA15)
/B0: U1.18 (PB0)
/B1: U1.19 (PB1)
/B2: U1.20 (PB2)
/B3: U1.39 (PB3)
/B4: U1.40 (PB4)
/B5: U1.41 (PB5)
/B6: U1.42 (PB6)
/B7: U1.43 (PB7)
/B8: U1.45 (PB8)
/B9: U1.46 (PB9)
/B10: U1.21 (PB10)
/B11: U1.22 (PB11)
/B12: U1.25 (PB12)
/B13: U1.26 (PB13)
/B14: U1.27 (PB14)
/B15: U1.28 (PB15)
/BOOT0: R1.2, SW1.2, U1.44 (BOOT0)
/C13: U1.2 (PC13)
/C14: U1.3 (PC14)
/C15: U1.4 (PC15)
/F0: U1.5 (PF0)
/F1: U1.6 (PF1)
/MCU_D+: U1.33 (PA12), U4.1 (I/O1)
/MCU_D-: U1.32 (PA11), U4.3 (I/O2)
/NRST: C7.1, U1.7 (NRST)
/USB_D+: J1.A6 (D+), J1.B6 (D+), U4.6 (I/O1)
/USB_D-: J1.A7 (D-), J1.B7 (D-), U4.4 (I/O2)
GND: C7.2, C8.2, C9.2, C10.1, C11.1, C12.1, C13.1, C14.1, C15.1, C16.1, C17.1, J1.A1 (GND), J1.A12 (GND), J1.B1 (GND), J1.B12 (GND), J1.S1 (SHIELD), R1.1, R2.2, R3.2, U1.8 (VSSA), U1.23 (VSS), U1.35 (VSS), U1.47 (VSS), U3.1 (GND), U4.2 (GND)
unnamed: J1.A5 (CC1), R2.1
unnamed: J1.B5 (CC2), R3.1
VBUS: F1.1, J1.A4 (VBUS), J1.A9 (VBUS), J1.B4 (VBUS), J1.B9 (VBUS), U4.5 (VBUS)

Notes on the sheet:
Hold when plugging in to enter bootloader mode.
STM32F072CBT6
USB-C
Mounting Holes
Decoupling Capacitors
Controller
ESD Protection
Power Flags
Voltage Step Down
Other
Bootloader Button
Matrix
Connector

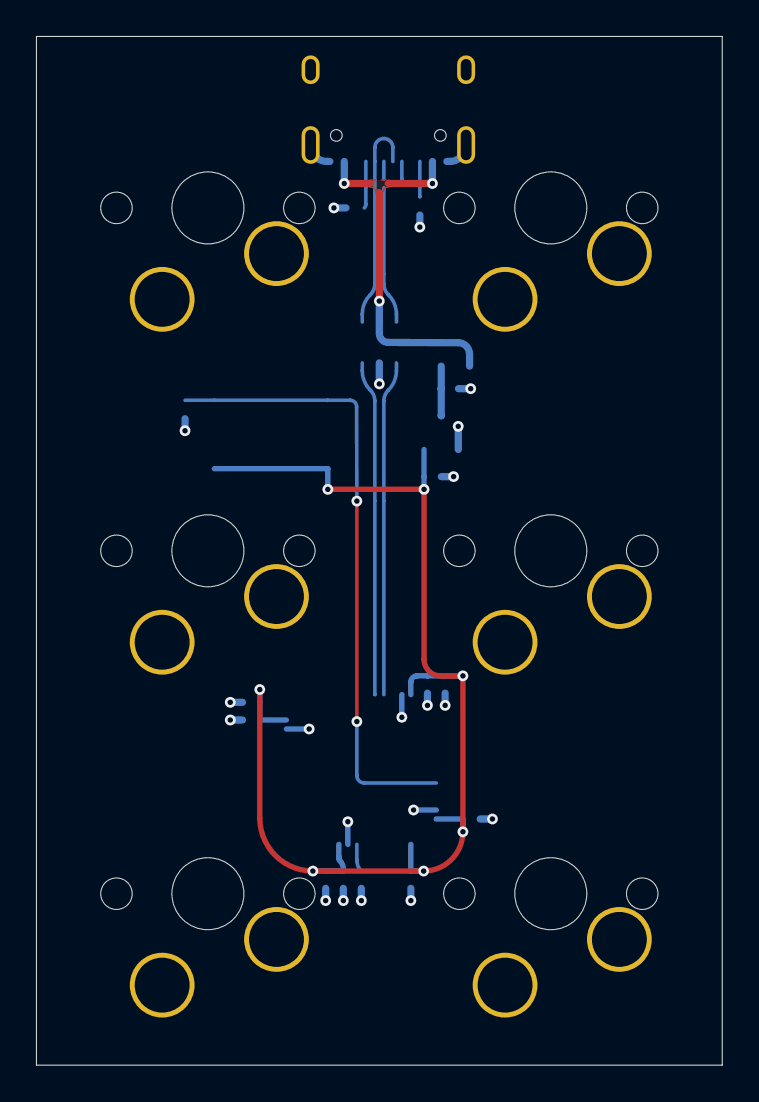
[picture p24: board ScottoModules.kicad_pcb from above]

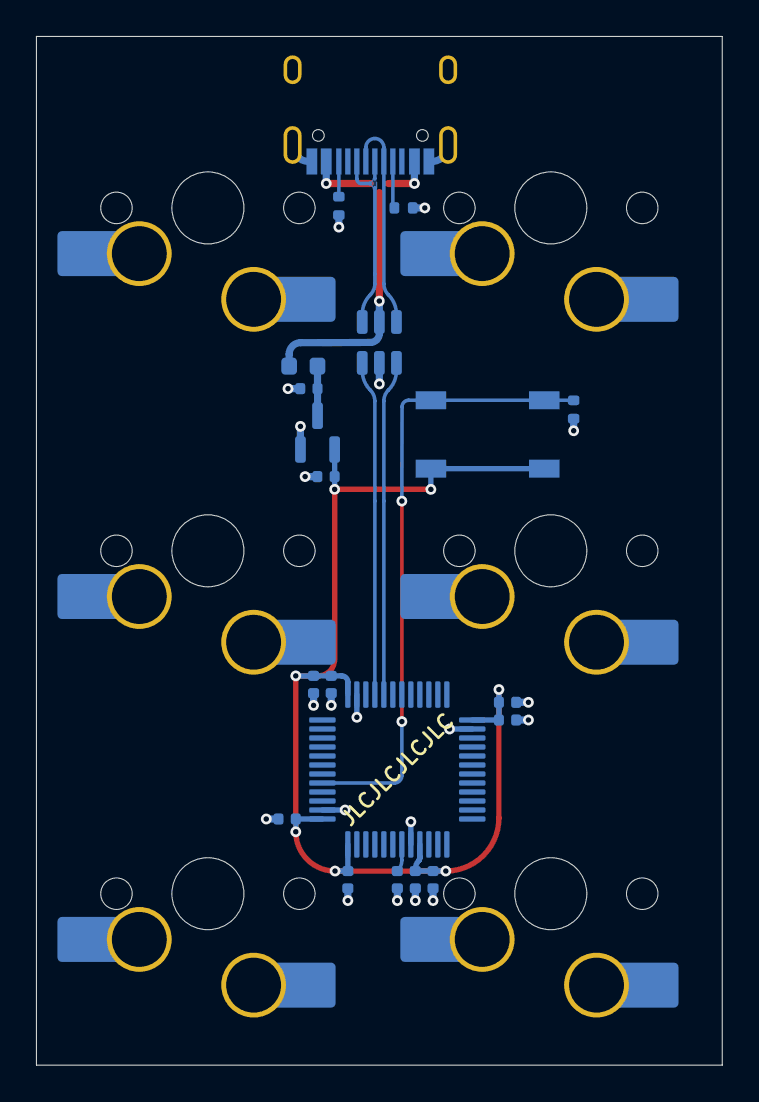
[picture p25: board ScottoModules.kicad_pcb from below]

Board: 4 copper layers, 38.1 x 57.2 mm, 20 parts (20 on the bottom side), 12 nets.

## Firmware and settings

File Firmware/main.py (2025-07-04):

import board
from kmk.kmk_keyboard import KMKKeyboard
from kmk.keys import KC
from kmk.scanners import DiodeOrientation
from kmk.extensions.encoder import EncoderHandler

keyboard = KMKKeyboard()

# GPIO setup from schematic
keyboard.col_pins = (
    board.GP0, board.GP1, board.GP2, board.GP3, board.GP4,
    board.GP5, board.GP6, board.GP7, board.GP8, board.GP9,
    board.GP10, board.GP11, board.GP12, board.GP13, board.GP14,  # Column 15 = GP14
)

keyboard.row_pins = (
    board.GP21,  # Row 1
    board.GP20,  # Row 2
    board.GP19,  # Row 3
    board.GP18,  # Row 4
    board.GP17,  # Row 5
)

keyboard.diode_orientation = DiodeOrientation.COL2ROW

# --- Encoder Setup ---
encoder_handler = EncoderHandler()
keyboard.extensions.append(encoder_handler)

# ENCA = GP27, ENCB = GP26
encoder_handler.rotary_encoder_pins = ((board.GP27, board.GP26),)
encoder_handler.rotary_encoder_map = (((KC.VOLU, KC.VOLD),),)

# --- Keymap Definition (5 rows x 15 columns) ---
keyboard.keymap = [
    [  # Layer 0
        KC.ESC,  KC.N1,   KC.N2,   KC.N3,   KC.N4,   KC.N5,   KC.N6,   KC.N7,   KC.N8,   KC.N9,   KC.N0,   KC.MINS, KC.EQL,  KC.BSPC, KC.MUTE,  # Row 1
        KC.TAB,  KC.Q,    KC.W,    KC.E,    KC.R,    KC.T,    KC.Y,    KC.U,    KC.I,    KC.O,    KC.P,    KC.LBRC, KC.RBRC, KC.BSLS, KC.DEL,   # Row 2
        KC.CAPS, KC.A,    KC.S,    KC.D,    KC.F,    KC.G,    KC.H,    KC.J,    KC.K,    KC.L,    KC.SCLN, KC.QUOT, KC.ENT,  KC.NO,   KC.NO,    # Row 3
        KC.LSFT, KC.Z,    KC.X,    KC.C,    KC.V,    KC.B,    KC.N,    KC.M,    KC.COMM, KC.DOT,  KC.SLSH, KC.RSFT, KC.UP,   KC.NO,   KC.NO,    # Row 4
        KC.LCTL, KC.LGUI, KC.LALT, KC.NO,   KC.NO,   KC.SPC,  KC.NO,   KC.NO,   KC.NO,   KC.RALT, KC.FN0,  KC.RCTL, KC.LEFT, KC.DOWN, KC.RGHT,  # Row 5
    ]
]

if __name__ == '__main__':
    keyboard.go()

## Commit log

2025-07-04 Adding stuff
    [0 (1.00u).3mf, 0 (16x16).3mf, 0 (18x17).3mf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]
2025-07-06 adding fixes
    [keeb assem v2.step, keeb assem v4.step, notakeeb top v3.step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]
2025-07-06 Add suggestions for approval a
    [keeb assem v4.step, keeb assem v6.step, notakeeb top v3.step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]
2025-07-07 Added to BOM
    [notakeeb BOM - Sheet1 (1).csv]
